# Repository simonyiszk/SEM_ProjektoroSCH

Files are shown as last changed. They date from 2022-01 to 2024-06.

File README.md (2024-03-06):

# RS232 Remote control
This project is created for wall mounted remote control of a projector's power settings and input selection.

## Protocol basics:
RS232 in a nutshell: https://docs.google.com/document/d/1p7Dz5NA0ECTMzfMRH148HRk15ERgRvAex5ETr_D8jeQ/edit?usp=sharing

## Project workflow:
- [x] Schematic design
- [ ] Firmwware developent
- [ ] Case design
- [ ] Protoype testing

## Project is made possible by Schönherz Elektronikai Műhely (SEM)

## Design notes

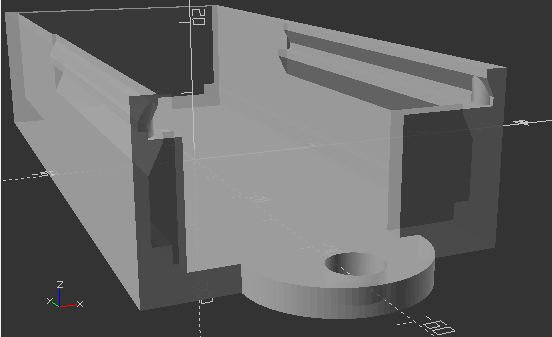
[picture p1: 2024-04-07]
Doboz/doboz_v5_becsusztatos_pattintos_3.jpg

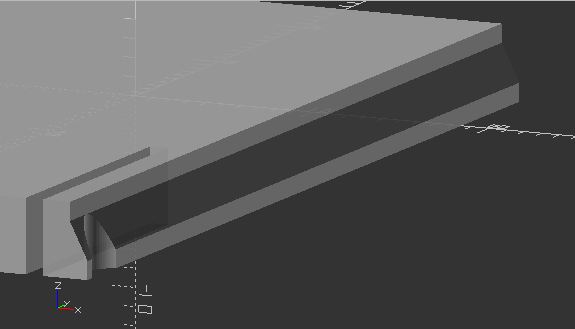
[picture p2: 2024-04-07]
Doboz/doboz_v5_becsusztatos_pattintos_2.jpg

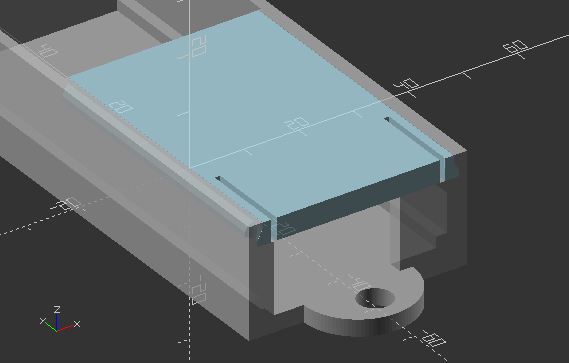
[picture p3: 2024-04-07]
Doboz/doboz_v5_becsusztatos_pattintos_4.jpg

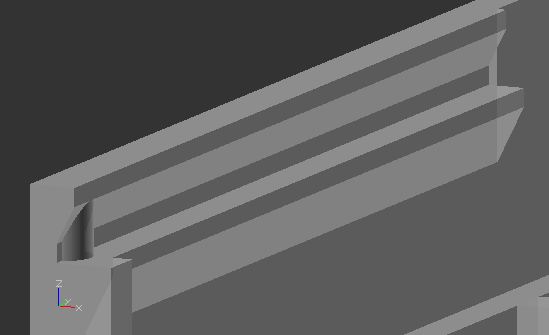
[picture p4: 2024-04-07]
Doboz/doboz_v5_becsusztatos_pattintos_1.jpg

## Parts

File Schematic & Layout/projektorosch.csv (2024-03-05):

Reference | Value | Footprint | Datasheet | Lcsc | Lscs | Qty
C1 | 0.1uF | Capacitor_SMD:C_0805_2012Metric_Pad1.18x1.45mm_HandSolder | ~ |  |  | 1
C2 | 0.1uF | Capacitor_SMD:C_0805_2012Metric_Pad1.18x1.45mm_HandSolder | ~ |  |  | 1
C3 | 0.1uF | Capacitor_SMD:C_0805_2012Metric_Pad1.18x1.45mm_HandSolder | ~ |  | C282730 | 1
C4 | 0.1uF | Capacitor_SMD:C_0805_2012Metric_Pad1.18x1.45mm_HandSolder | ~ |  |  | 1
C5 | 0.1uF | Capacitor_SMD:C_0805_2012Metric_Pad1.18x1.45mm_HandSolder | ~ |  |  | 1
C6 | 0.1uF | Capacitor_SMD:C_0805_2012Metric_Pad1.18x1.45mm_HandSolder | ~ |  |  | 1
C7 | 0.1uF | Capacitor_SMD:C_0805_2012Metric_Pad1.18x1.45mm_HandSolder | ~ |  |  | 1
C8 | 0.1uF | Capacitor_SMD:C_0805_2012Metric_Pad1.18x1.45mm_HandSolder | ~ |  | C6641151 | 1
C9 | 22pF | Capacitor_SMD:C_0805_2012Metric_Pad1.18x1.45mm_HandSolder | ~ |  | C190088 | 1
C10 | 22pF | Capacitor_SMD:C_0805_2012Metric_Pad1.18x1.45mm_HandSolder | ~ |  |  | 1
J1 | Power | Connector_Phoenix_MC:PhoenixContact_MC_1,5_2-G-3.5_1x02_P3.50mm_Horizontal | ~ |  |  | 1
J2 | RS232 | Connector_Phoenix_MC:PhoenixContact_MC_1,5_3-G-3.5_1x03_P3.50mm_Horizontal | ~ |  |  | 1
J3 | Programmer | Connector_PinHeader_2.54mm:PinHeader_1x06_P2.54mm_Vertical | ~ |  |  | 1
J4 | ISP | Connector_PinHeader_2.54mm:PinHeader_2x03_P2.54mm_Vertical | ~ |  |  | 1
R1 | 150 | Resistor_SMD:R_0805_2012Metric_Pad1.20x1.40mm_HandSolder | ~ |  |  | 1
R2 | 150 | Resistor_SMD:R_0805_2012Metric_Pad1.20x1.40mm_HandSolder | ~ |  |  | 1
R3 | 150 | Resistor_SMD:R_0805_2012Metric_Pad1.20x1.40mm_HandSolder | ~ |  |  | 1
R4 | 150 | Resistor_SMD:R_0805_2012Metric_Pad1.20x1.40mm_HandSolder | ~ |  |  | 1
R5 | 10k | Resistor_SMD:R_0805_2012Metric_Pad1.20x1.40mm_HandSolder | ~ |  |  | 1
R6 | 10k | Resistor_SMD:R_0805_2012Metric_Pad1.20x1.40mm_HandSolder | ~ |  |  | 1
R7 | 10k | Resistor_SMD:R_0805_2012Metric_Pad1.20x1.40mm_HandSolder | ~ |  |  | 1
R8 | 10k | Resistor_SMD:R_0805_2012Metric_Pad1.20x1.40mm_HandSolder | ~ |  |  | 1
R9 | 10k | Resistor_SMD:R_0805_2012Metric_Pad1.20x1.40mm_HandSolder | ~ |  |  | 1
SW1 | Input 1 | Library:Marquardt 64250101 | ~ |  |  | 1
SW2 | Input 2 | Library:Marquardt 64250101 | ~ |  |  | 1
SW3 | Power off | Library:Marquardt 64250101 | ~ |  |  | 1
SW4 | Power on | Library:Marquardt 64250101 | ~ |  |  | 1
SW5 | Reset | Button_Switch_SMD:SW_Push_1P1T_NO_6x6mm_H9.5mm | ~ |  | C255812 | 1
TP1 | 5V | TestPoint:TestPoint_Pad_D2.5mm | ~ |  |  | 1
TP2 | GND | TestPoint:TestPoint_Pad_D2.5mm | ~ |  |  | 1
TP3 | 232-RX | TestPoint:TestPoint_Pad_D2.5mm | ~ |  |  | 1
TP4 | 232-TX | TestPoint:TestPoint_Pad_D2.5mm | ~ |  |  | 1
U1 | MAX232 | Package_SO:SOP-16_3.9x9.9mm_P1.27mm | http://www.ti.com/lit/ds/symlink/max232.pdf |  | C519083 | 1
U2 | ATmega328P-A | Package_QFP:TQFP-32_7x7mm_P0.8mm | http://ww1.microchip.com/downloads/en/DeviceDoc/ATmega328_P%20AVR%20MCU%20with%20picoPower%20Technology%20Data%20Sheet%2040001984A.pdf |  | C132230 | 1
Y1 | 16MHz | Crystal:Crystal_SMD_HC49-SD_HandSoldering | ~ | C2975360 |  | 1

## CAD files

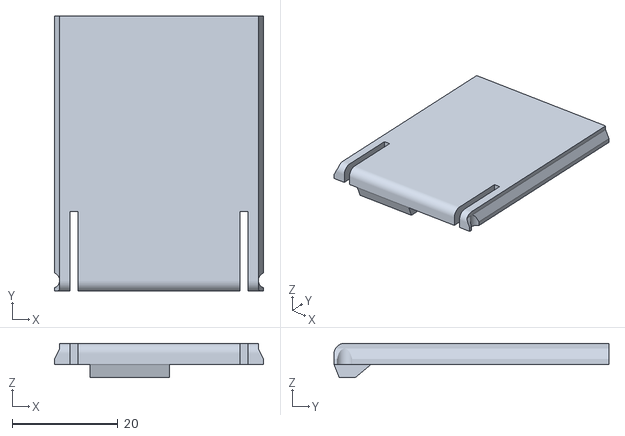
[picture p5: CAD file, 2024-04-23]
Doboz/doboz_v6_felso.stl
39.6 x 52.0 x 6.50

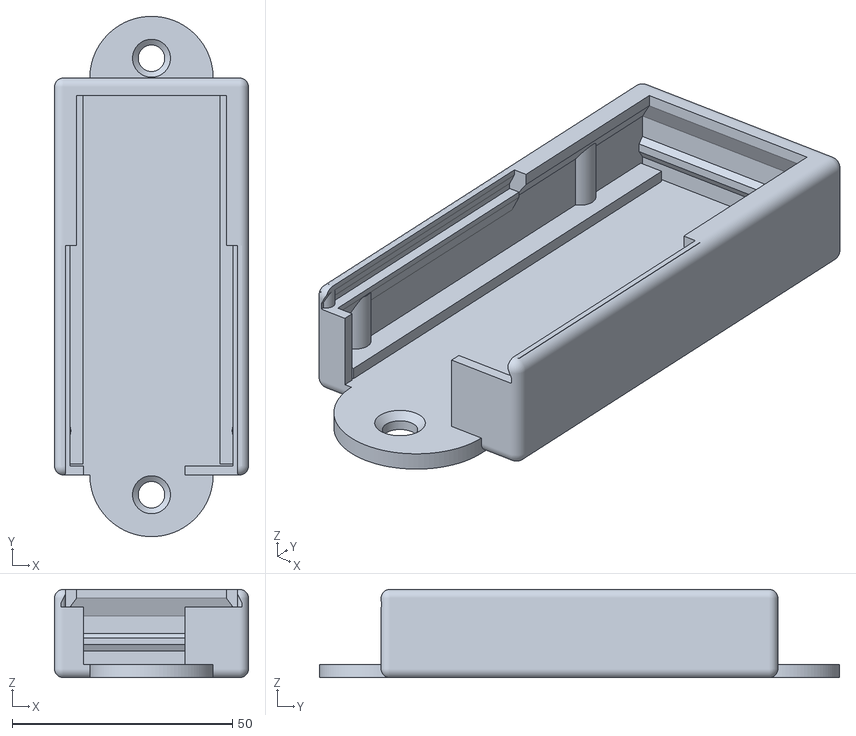
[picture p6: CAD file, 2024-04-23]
Doboz/doboz_v6_also.stl
44.0 x 118.0 x 20.0

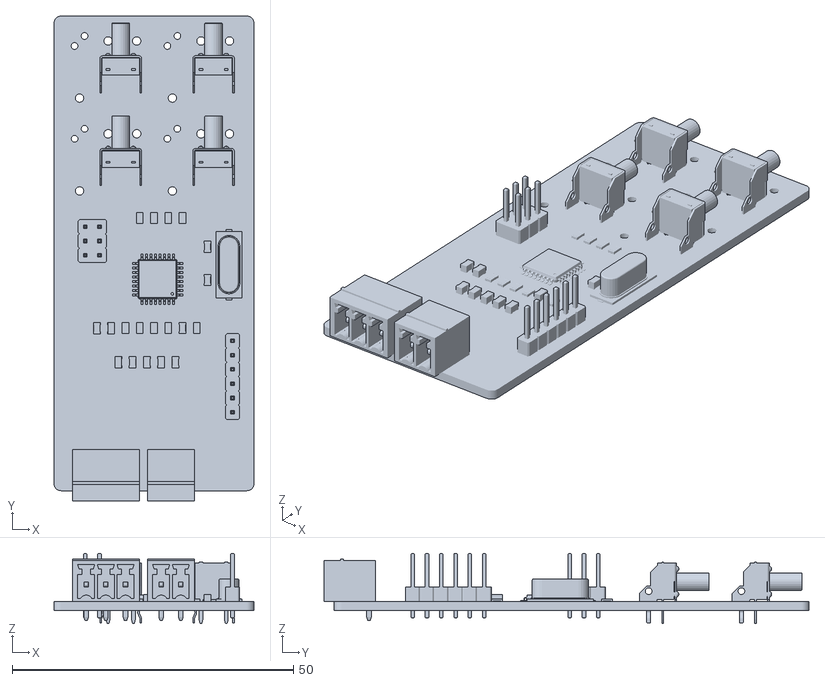
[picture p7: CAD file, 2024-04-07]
Doboz/doboz_v4-elektronika_3d.stl
35.6 x 86.3 x 12.5

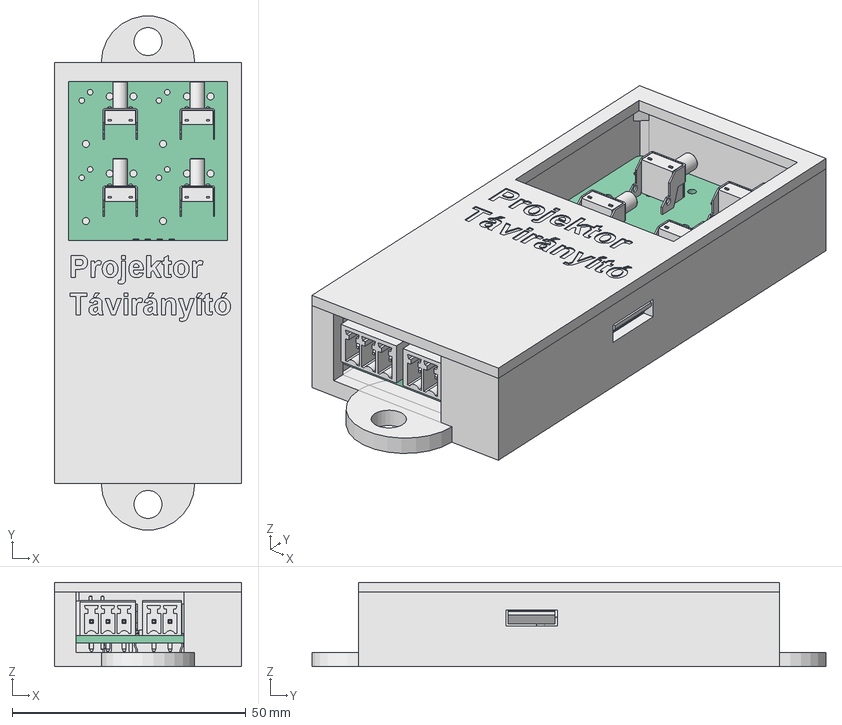
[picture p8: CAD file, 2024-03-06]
Doboz/doboz_v4.FCStd
40.0 x 109.9 x 18.0 mm
Pcb_c95c
J2_MC_01x03_G_3_5mm_12e7bac8dbaf
R8_R_0805_2012Metric_695cc4dfc1c9 x 9
Y1_Crystal_SMD_HC49-SD_3ddabce48a06
C1_C_0805_2012Metric_832210f2bbc2 x 10
U2_TQFP_32_7x7mm_P08mm_a250dbf983b6
J1_MC_01x02_G_3_5mm_f8f39d346681
SW4_SW_Tactile_SPST_Angled_PTS645Vx83-2LFS_4b6979eed0d8 x 4
J3_PinHeader_1x06_P254mm_Vertical_726634c3bc6e
J4_PinHeader_2x03_P254mm_Vertical_2c30eb3d481b
Also
Felso2

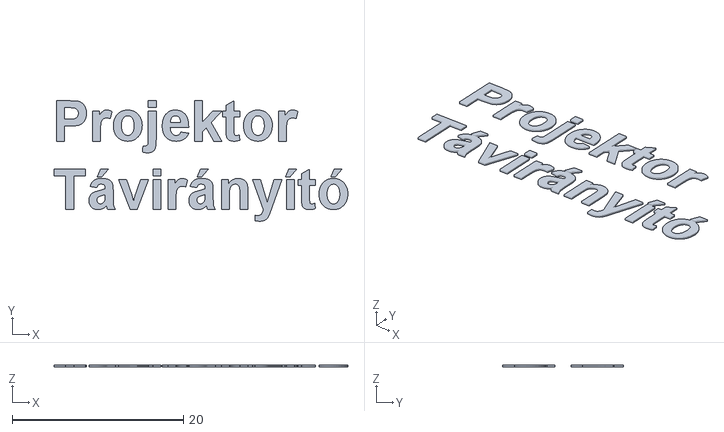
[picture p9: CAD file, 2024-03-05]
Doboz/doboz_v4-Felirat001.stl
34.4 x 14.1 x 0.2

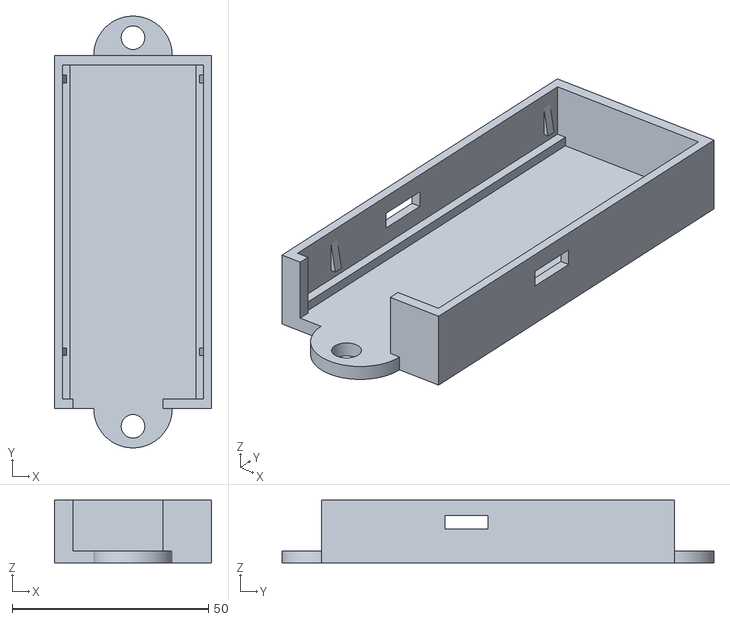
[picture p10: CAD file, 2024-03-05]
Doboz/doboz_v4-Also2.stl
40.0 x 110.0 x 16.0

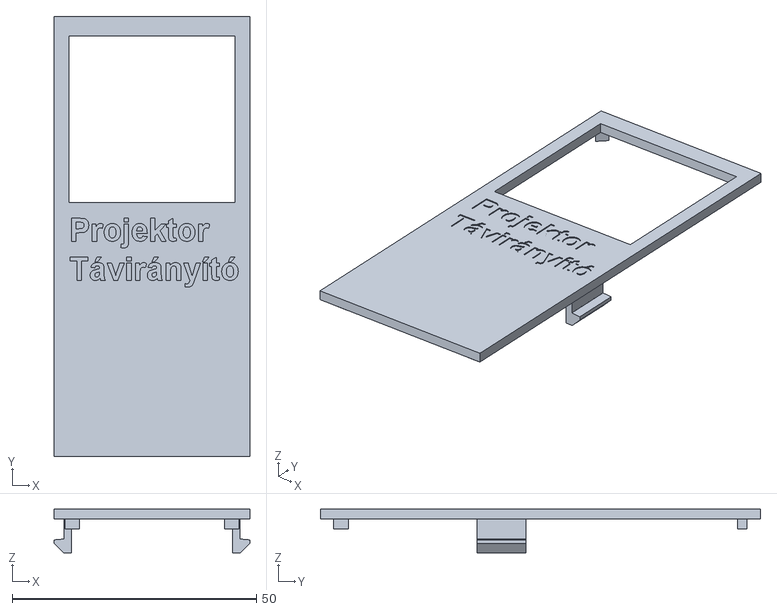
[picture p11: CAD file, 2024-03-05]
Doboz/doboz_v4-Felso2.stl
40.0 x 90.0 x 8.90

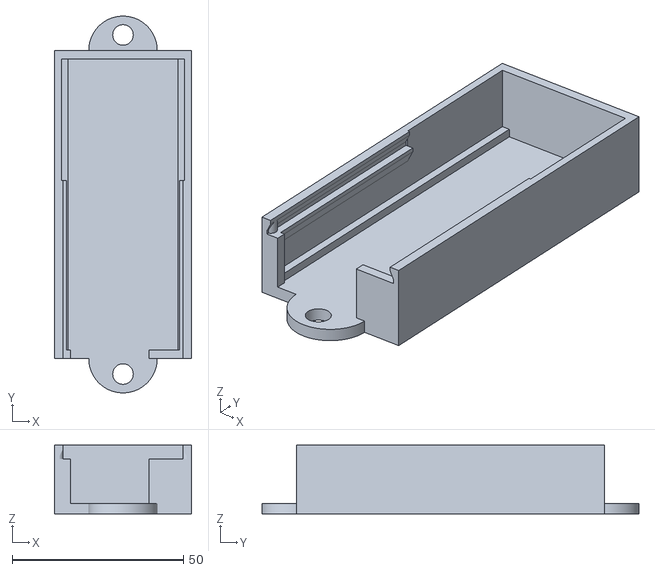
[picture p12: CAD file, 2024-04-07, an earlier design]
Doboz/doboz_v5_also.stl
40.0 x 110.0 x 20.0

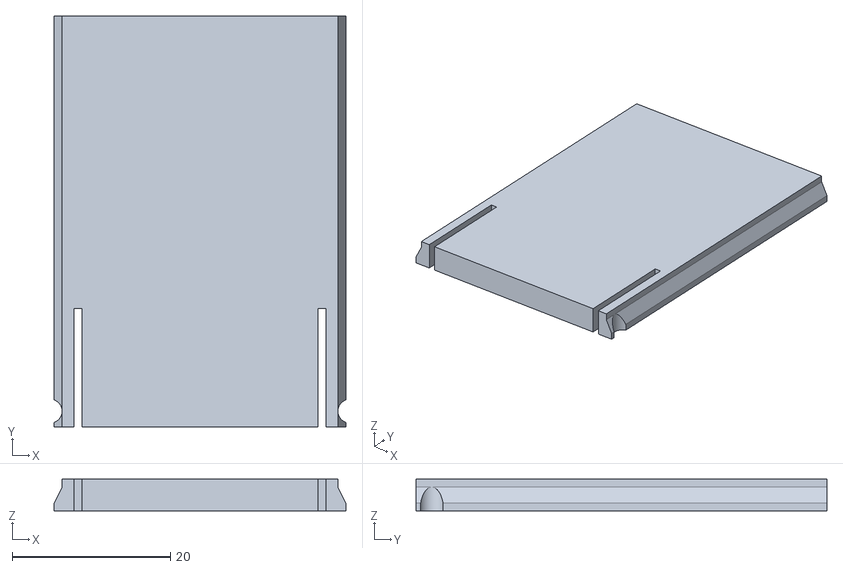
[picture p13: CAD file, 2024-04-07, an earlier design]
Doboz/doboz_v5_felso.stl
36.9 x 52.0 x 4.00

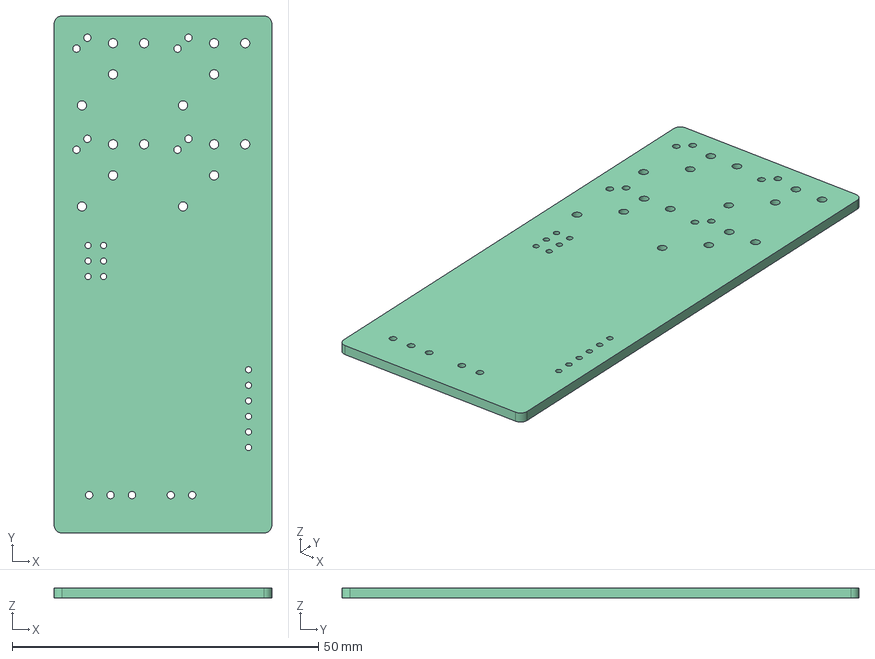
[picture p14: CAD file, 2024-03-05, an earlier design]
Doboz/doboz_v1.FCStd
35.6 x 84.5 x 1.60 mm

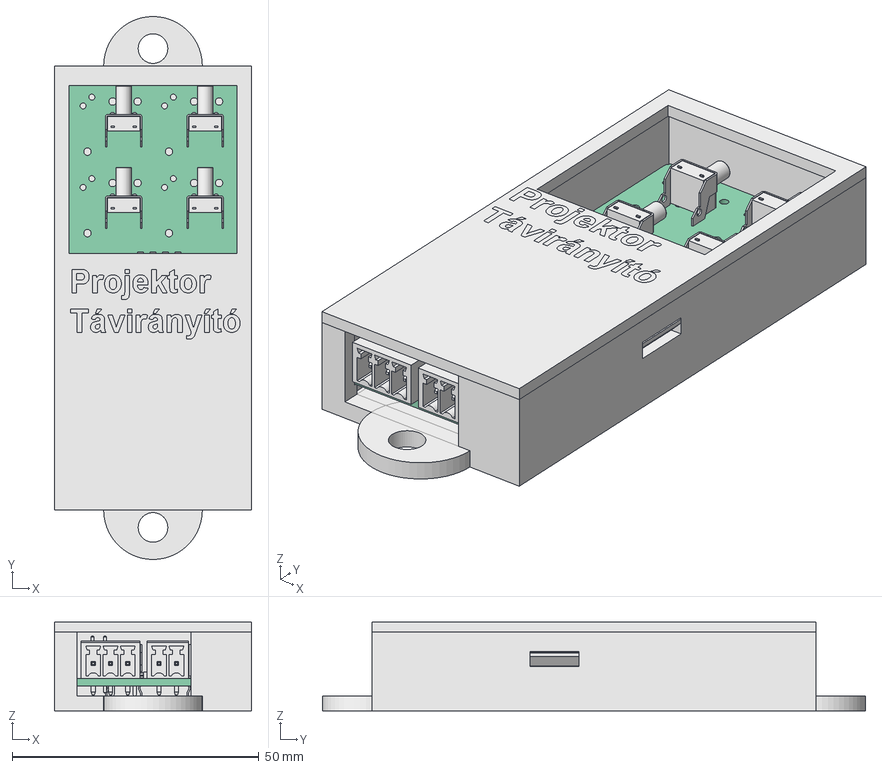
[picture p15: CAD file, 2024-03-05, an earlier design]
Doboz/doboz_v3.FCStd
40.0 x 110.0 x 20.0 mm
Pcb_c95c
J2_MC_01x03_G_3_5mm_12e7bac8dbaf
R8_R_0805_2012Metric_695cc4dfc1c9 x 9
Y1_Crystal_SMD_HC49-SD_3ddabce48a06
C1_C_0805_2012Metric_832210f2bbc2 x 10
U2_TQFP_32_7x7mm_P08mm_a250dbf983b6
J1_MC_01x02_G_3_5mm_f8f39d346681
SW4_SW_Tactile_SPST_Angled_PTS645Vx83-2LFS_4b6979eed0d8 x 4
J3_PinHeader_1x06_P254mm_Vertical_726634c3bc6e
J4_PinHeader_2x03_P254mm_Vertical_2c30eb3d481b
Also
Felso
ShapeString
ShapeString001

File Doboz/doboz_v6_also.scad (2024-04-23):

//OpenSCAD source code
//https://openscad.org

//color("red",0.8) translate([0,0,0]) import("doboz_v4-Also2.stl");
//color("pink",0.8)translate([0,0,0]) import("doboz_v4-Felso2.stl");
color("lightgreen",0.8) translate([0,0,0]) import("doboz_v4-elektronika_3d.stl");
color("lightblue",0.8) translate([0,0,0]) import("doboz_v6_felso.stl");

//HA JOBBAN ÁT SZERETNÉD LÁTNI MI HOGY VAN, KAPCSOLD BE EZEKET:
$ATTEKINTO_NEZET=false;
$FELBEVAGOTT_NEZET=false;

$fn=15; //ÍV FELBONTÁS - STL-BE EXPORTÁLÁS ELŐTT VEDD FEL PL. 100-ra!
//(jelentősen több ideig fog generálni, úgyhogy az EXPORTÁLÁS LÉPÉSEI:
//kikommenteled az importokat; átírod $fn=100-ra; rányomsz a "render" gombra (vagy F6); megvárod míg legenerálja; File->Export; aztán Ctrl+Z amennyiszer kell)

//Szélesség állításnál az alsó nyáktartó peremeket kézzel kell igazítani
//
//Hosszúság állításánál  fenti részt tartó vezetősíneket és a gomb mlletti takrókt kézzel kell átméretezni
//
//A felső rész módosításakor ne felejtsd el átmásolni innen a konstansokat!
//

$lekerekites=2;
$belso_hossz=86;
$belso_szel=40;
$kulso_mag=20;
$anyagvastagsag_oldalfal=2;
$anyagvastagsag_alja=3;
$henger_sugar=14;
$henger_luk=3;
$felso_resz_hossz=50; //+anyagvastagsag_oldalfal

color("#b0b0b0",0.8)
render(){


difference(){//alsó rész mínusz felső rész
	//alsó rész:
	union(){
		
		
		difference(){
			union(){
				//alap téglatest, amiből ki lesz vonva a belső rész:
				translate([0,0,10])
				if($ATTEKINTO_NEZET==false)
					cube([$belso_szel+2*$anyagvastagsag_oldalfal,$belso_hossz+2*$anyagvastagsag_oldalfal,$kulso_mag], center=true);

				//fél hengerek a talpon a rögzítéshez:
				translate([0,$belso_hossz/2+$anyagvastagsag_oldalfal,$anyagvastagsag_alja/2])
					difference(){
						cylinder(r=$henger_sugar,h=$anyagvastagsag_alja,center=true);
						translate([0,4.5,0])
							cylinder(r=$henger_luk,h=$anyagvastagsag_alja,center=true);
						//felfogató csavar süllyesztés (45 fokos kúp):
						translate([0,4.5,+2.2])
							cylinder(r1=0,r2=10,h=10,center=true);
					}
				translate([0,-$belso_hossz/2-$anyagvastagsag_oldalfal,$anyagvastagsag_alja/2])
					difference(){
						cylinder(r=$henger_sugar,h=$anyagvastagsag_alja,center=true);
						translate([0,-4.5,0])
							cylinder(r=$henger_luk,h=$anyagvastagsag_alja,center=true);
						translate([0,-4.5,+2.2])
							cylinder(r1=0,r2=10,h=10,center=true);
					}
			}
			
			//oldalfalból kivágott hely csatlakozóknak:
			translate([-15.4,-45.001,$anyagvastagsag_alja])
				cube([23,2.502,30],center=false);
			
			//középső üreg:
			translate([0,0,$anyagvastagsag_alja+1000/2])
				cube([$belso_szel,$belso_hossz,1000], center=true);
			//lekerekítések:
			{
			//bal oldal:
			
			//alsó lekerekítések:
			translate([(-$belso_szel/2)-$anyagvastagsag_oldalfal+$lekerekites/2,0,$lekerekites/2])
				el_lekerekites_negativ($lekerekites,$belso_hossz+2*$anyagvastagsag_oldalfal);
			translate([-$belso_szel/2,-$belso_hossz/2-$anyagvastagsag_oldalfal+$lekerekites/2,$lekerekites/2])
				rotate([0,0,90])
					el_lekerekites_negativ($lekerekites,2*($belso_szel/2-$henger_sugar));
			translate([-$belso_szel/2,+$belso_hossz/2+$anyagvastagsag_oldalfal-$lekerekites/2,$lekerekites/2])
				rotate([0,0,-90])
					el_lekerekites_negativ($lekerekites,2*($belso_szel/2-$henger_sugar));
			translate([-$belso_szel/2-$anyagvastagsag_oldalfal+$lekerekites/2,-$belso_hossz/2-$anyagvastagsag_oldalfal+$lekerekites/2,$lekerekites/2])
				rotate([0,0,0])
					sarok_legombolyites_negativ($lekerekites);
			translate([-$belso_szel/2-$anyagvastagsag_oldalfal+$lekerekites/2,+$belso_hossz/2+$anyagvastagsag_oldalfal-$lekerekites/2,$lekerekites/2])
				rotate([0,0,-90])
					sarok_legombolyites_negativ($lekerekites);
			//oldalsó lekerekítések:
			translate([-$belso_szel/2-$anyagvastagsag_oldalfal+$lekerekites/2,-$belso_hossz/2-$anyagvastagsag_oldalfal+$lekerekites/2,$kulso_mag/2])
				rotate([90,0,90])
					el_lekerekites_negativ($lekerekites,$kulso_mag);
			translate([-$belso_szel/2-$anyagvastagsag_oldalfal+$lekerekites/2,+$belso_hossz/2+$anyagvastagsag_oldalfal-$lekerekites/2,$kulso_mag/2])
				rotate([90,0,0])
					el_lekerekites_negativ($lekerekites,$kulso_mag);
			//felső lekerekítések:
			translate([(-$belso_szel/2)-$anyagvastagsag_oldalfal+$lekerekites/2,0,$kulso_mag-$lekerekites/2])
				rotate([0,90,0])
					el_lekerekites_negativ($lekerekites,$belso_hossz+2*$anyagvastagsag_oldalfal);
			translate([-$belso_szel/2-$anyagvastagsag_oldalfal,-$belso_hossz/2-$anyagvastagsag_oldalfal+$lekerekites/2,$kulso_mag-$lekerekites/2])
				rotate([0,90,90])
					el_lekerekites_negativ($lekerekites,$belso_szel/2+$anyagvastagsag_oldalfal);
			translate([0,+$belso_hossz/2+$anyagvastagsag_oldalfal-$lekerekites/2,$kulso_mag-$lekerekites/2])
				rotate([0,90,-90])
					el_lekerekites_negativ($lekerekites,$belso_szel+2*$anyagvastagsag_oldalfal);
			translate([-$belso_szel/2-$anyagvastagsag_oldalfal+$lekerekites/2,-$belso_hossz/2-$anyagvastagsag_oldalfal+$lekerekites/2,$kulso_mag-$lekerekites/2])
				rotate([0,90,0])
					sarok_legombolyites_negativ($lekerekites);
			translate([-$belso_szel/2-$anyagvastagsag_oldalfal+$lekerekites/2,+$belso_hossz/2+$anyagvastagsag_oldalfal-$lekerekites/2,$kulso_mag-$lekerekites/2])
				rotate([0,90,-90])
					sarok_legombolyites_negativ($lekerekites);
			
			
			//jobb oldal:
			mirror([1,0,0]){
			
			
			//alsó lekerekítések:
			translate([(-$belso_szel/2)-$anyagvastagsag_oldalfal+$lekerekites/2,0,$lekerekites/2])
				el_lekerekites_negativ($lekerekites,$belso_hossz+2*$anyagvastagsag_oldalfal);
			translate([-$belso_szel/2,-$belso_hossz/2-$anyagvastagsag_oldalfal+$lekerekites/2,$lekerekites/2])
				rotate([0,0,90])
					el_lekerekites_negativ($lekerekites,2*($belso_szel/2-$henger_sugar));
			translate([-$belso_szel/2,+$belso_hossz/2+$anyagvastagsag_oldalfal-$lekerekites/2,$lekerekites/2])
				rotate([0,0,-90])
					el_lekerekites_negativ($lekerekites,2*($belso_szel/2-$henger_sugar));
			translate([-$belso_szel/2-$anyagvastagsag_oldalfal+$lekerekites/2,-$belso_hossz/2-$anyagvastagsag_oldalfal+$lekerekites/2,$lekerekites/2])
				rotate([0,0,0])
					sarok_legombolyites_negativ($lekerekites);
			translate([-$belso_szel/2-$anyagvastagsag_oldalfal+$lekerekites/2,+$belso_hossz/2+$anyagvastagsag_oldalfal-$lekerekites/2,$lekerekites/2])
				rotate([0,0,-90])
					sarok_legombolyites_negativ($lekerekites);
			//oldalsó lekerekítések:
			translate([-$belso_szel/2-$anyagvastagsag_oldalfal+$lekerekites/2,-$belso_hossz/2-$anyagvastagsag_oldalfal+$lekerekites/2,$kulso_mag/2])
				rotate([90,0,90])
					el_lekerekites_negativ($lekerekites,$kulso_mag);
			translate([-$belso_szel/2-$anyagvastagsag_oldalfal+$lekerekites/2,+$belso_hossz/2+$anyagvastagsag_oldalfal-$lekerekites/2,$kulso_mag/2])
				rotate([90,0,0])
					el_lekerekites_negativ($lekerekites,$kulso_mag);
			//felső lekerekítések:
			translate([(-$belso_szel/2)-$anyagvastagsag_oldalfal+$lekerekites/2,0,$kulso_mag-$lekerekites/2])
				rotate([0,90,0])
					el_lekerekites_negativ($lekerekites,$belso_hossz+2*$anyagvastagsag_oldalfal);
			translate([-$belso_szel/2-$anyagvastagsag_oldalfal,-$belso_hossz/2-$anyagvastagsag_oldalfal+$lekerekites/2,$kulso_mag-$lekerekites/2])
				rotate([0,90,90])
					el_lekerekites_negativ($lekerekites,$belso_szel/2+$anyagvastagsag_oldalfal);
			translate([0,+$belso_hossz/2+$anyagvastagsag_oldalfal-$lekerekites/2,$kulso_mag-$lekerekites/2])
				rotate([0,90,-90])
					el_lekerekites_negativ($lekerekites,$belso_szel+2*$anyagvastagsag_oldalfal);
			translate([-$belso_szel/2-$anyagvastagsag_oldalfal+$lekerekites/2,-$belso_hossz/2-$anyagvastagsag_oldalfal+$lekerekites/2,$kulso_mag-$lekerekites/2])
				rotate([0,90,0])
					sarok_legombolyites_negativ($lekerekites);
			translate([-$belso_szel/2-$anyagvastagsag_oldalfal+$lekerekites/2,+$belso_hossz/2+$anyagvastagsag_oldalfal-$lekerekites/2,$kulso_mag-$lekerekites/2])
				rotate([0,90,-90])
					sarok_legombolyites_negativ($lekerekites);
			}//mirror (lekerekítések)
			}//lekerekítések
		}//difference
		//felső részt alulról tartó háromszög sávok:
		translate([-$belso_szel/2-0,7,12])
			rotate([90,0,0])
				linear_extrude(50)
				polygon([ [0,0], [1.5,3], [1.5,4], [0,4] ]);
		mirror([1,0,0])
		translate([-$belso_szel/2-0,7,12])
			rotate([90,0,0])
				linear_extrude(50)
				polygon([ [0,0], [1.5,3], [1.5,4], [0,4] ]);
		//felső részt felülrőlról tartó háromszög sávok:
		translate([-$belso_szel/2-0.5,7,17])
			rotate([90,0,0])
				linear_extrude(50)
				polygon([ [0,0], [1,2], [1,3], [0,3] ]);
		mirror([1,0,0])
		translate([-$belso_szel/2-0.5,7,17])
			rotate([90,0,0])
				linear_extrude(50)
				polygon([ [0,0], [1,2], [1,3], [0,3] ]);
		//belső perem lent két oldalt:
		$perem_szel=4.5;
		$perem_mag=2;
		translate([-$belso_szel/2+$perem_szel/2,0,+$anyagvastagsag_alja+$perem_mag/2])
			cube([$perem_szel,85,2], center=true);
		translate([+$belso_szel/2-$perem_szel/2,0,+$anyagvastagsag_alja+$perem_mag/2])
			cube([$perem_szel,85,2], center=true);
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

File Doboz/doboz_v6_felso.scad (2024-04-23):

//OpenSCAD source code
//https://openscad.org

//import("C:/SEM_Simonyi/SEM_ProjektoroSCH-main/Doboz/doboz_v5_also.scad");

$fn=100;

//Mennyivel legyen keskenyebb a nyomtatott felső darab az alsóban neki kialakított helynél (x2, azaz mindkét oldalból levon ennyit)? Ha nem fér be, feszül, akkor növeld az értéket.
$oldalso_kisebbites=0.7;

$lekerekites=2;
$belso_hossz=86;
$belso_szel=40;
$kulso_mag=20;
$anyagvastagsag_oldalfal=2;
$anyagvastagsag_alja=3;
$henger_sugar=14;
$henger_luk=3;
$felso_resz_hossz=50; //+anyagvastagsag_oldalfal

translate([0,-$belso_hossz/2-$anyagvastagsag_oldalfal,16])
color("#b0b0b0",0.8)
render(){
//TODO: hosszúság rövidebbre vétele, hogy biztosan bepattanjon

difference(){
	//trapéz-szerű alap:
	union(){
		translate([0,$felso_resz_hossz+$anyagvastagsag_oldalfal,0])
			rotate([90,0,0])
				linear_extrude($felso_resz_hossz+$anyagvastagsag_oldalfal)
				polygon([ 
					[-$belso_szel/2-0.5+$oldalso_kisebbites,0],
					[+$belso_szel/2+0.5-$oldalso_kisebbites,0],
					[+$belso_szel/2+0.5-$oldalso_kisebbites,1],
					[+$belso_szel/2-0.5-$oldalso_kisebbites,3],
					[+$belso_szel/2-0.5-$oldalso_kisebbites,4],
					[-$belso_szel/2+0.5+$oldalso_kisebbites,4],
					[-$belso_szel/2+0.5+$oldalso_kisebbites,3],
					[-$belso_szel/2-0.5+$oldalso_kisebbites,1] ]);
		//csatlakozókat leszorító kiálló rész az alján
		translate([-13,0,0])
			rotate([90,0,0])
			rotate([0,90,0])
				linear_extrude(15)
				polygon([ 
					[0,0],
					[1,-2.5],
					[4,-2.5],
					[7,0] ]);
	}

	//fél henger pöckök a rögzítéshez:
	translate([$belso_szel/2+$anyagvastagsag_oldalfal/2-$oldalso_kisebbites,2,1.5])
		difference(){
			cylinder(r=1.5, h=4, center=true);
			translate([0,-5,-5])cube([10,10,10]);
		}
	mirror([1,0,0])
	translate([$belso_szel/2+$anyagvastagsag_oldalfal/2-$oldalso_kisebbites,2,1.5])
		difference(){
			cylinder(r=1.5, h=4, center=true);
			translate([0,-5,-5])cube([10,10,10]);
		}
	//bevágások a hajlékonysághoz a rögzítésnél
	translate([0.40*$belso_szel-$oldalso_kisebbites,0,0])
		cube([1.5,15,4]);
	mirror([1,0,0])
	translate([0.40*$belso_szel-$oldalso_kisebbites,0,0])
		cube([1.5,15,4]);
	//felső lekerekítés a elejénél:
	translate([0,$lekerekites/2,4-$lekerekites/2])
		rotate([0,180,-90])
			el_lekerekites_negativ($lekerekites,$belso_szel+2*$anyagvastagsag_oldalfal);
}


}//render

module sarok_legombolyites_negativ(r,center=true){
	if(center==true){
		translate([r/2,r/2,r/2])
		rotate([0,90,180])
			difference(){
				cube(r);
				sphere(r);
			}
	}else if(center==false){
		rotate([0,90,180])
			difference(){
				cube(r);
				sphere(r);
			}
	}
}
module el_lekerekites_negativ(r,hossz,center=true){
	if(center==true){
	translate([r/2,-hossz/2,r/2])
		rotate([0,180,0])
			difference(){
			cube([r,hossz,r]);
			translate([0,-0.5,0])
				rotate([-90,0,0])
					cylinder(hossz+1, r, r);
			}
	}else if(center==false){
	translate([0,0,0])
		rotate([0,180,0])
			difference(){
			cube([r,hossz,r]);
			translate([0,-0.5,0])
				rotate([-90,0,0])
					cylinder(hossz+1, r, r);
			}
	}
}

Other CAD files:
Doboz/doboz_v2.FCStd
Doboz/doboz_v5_also.scad
Doboz/doboz_v5_felso.scad

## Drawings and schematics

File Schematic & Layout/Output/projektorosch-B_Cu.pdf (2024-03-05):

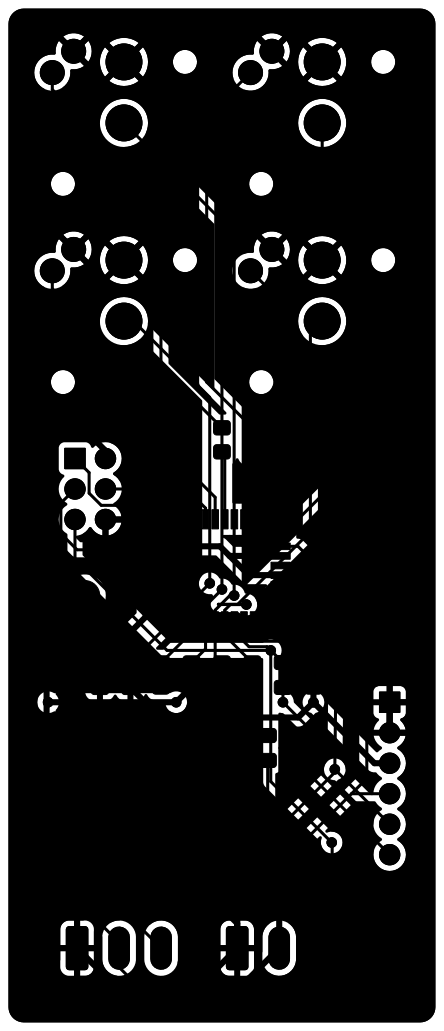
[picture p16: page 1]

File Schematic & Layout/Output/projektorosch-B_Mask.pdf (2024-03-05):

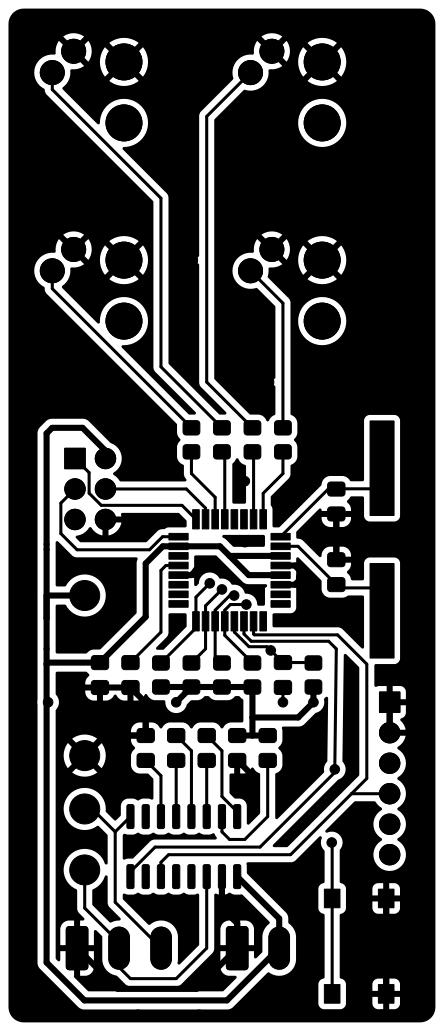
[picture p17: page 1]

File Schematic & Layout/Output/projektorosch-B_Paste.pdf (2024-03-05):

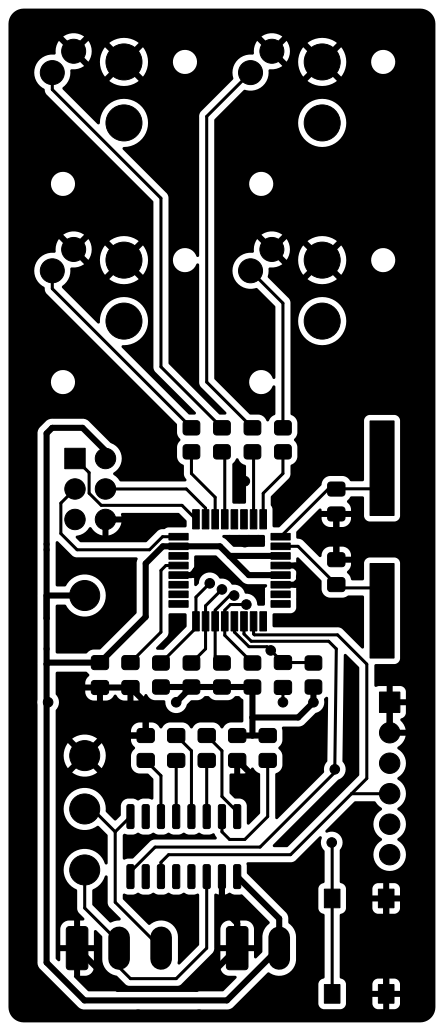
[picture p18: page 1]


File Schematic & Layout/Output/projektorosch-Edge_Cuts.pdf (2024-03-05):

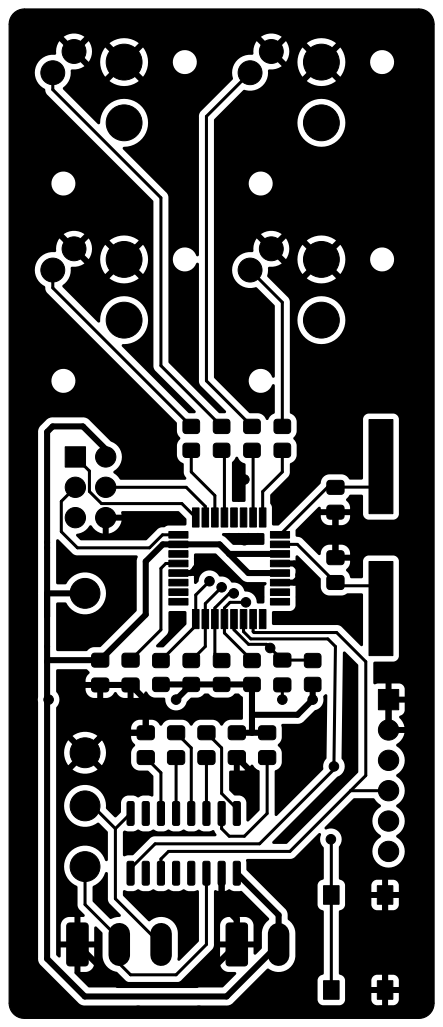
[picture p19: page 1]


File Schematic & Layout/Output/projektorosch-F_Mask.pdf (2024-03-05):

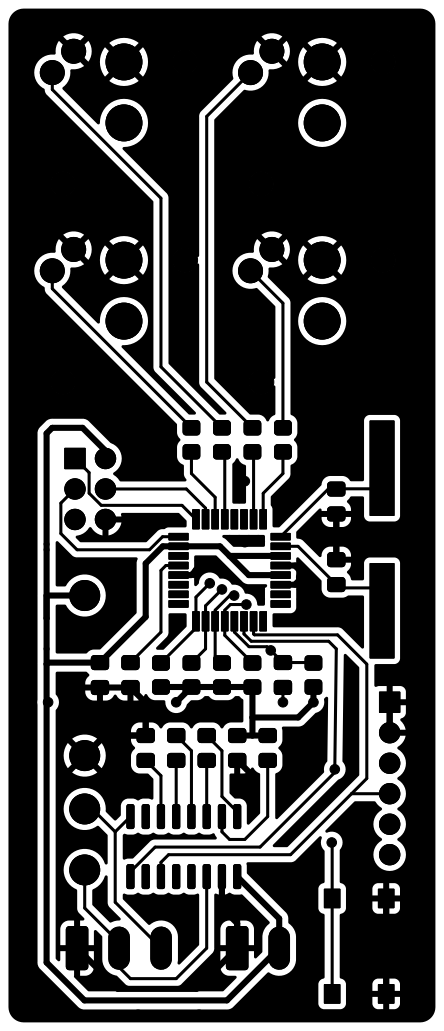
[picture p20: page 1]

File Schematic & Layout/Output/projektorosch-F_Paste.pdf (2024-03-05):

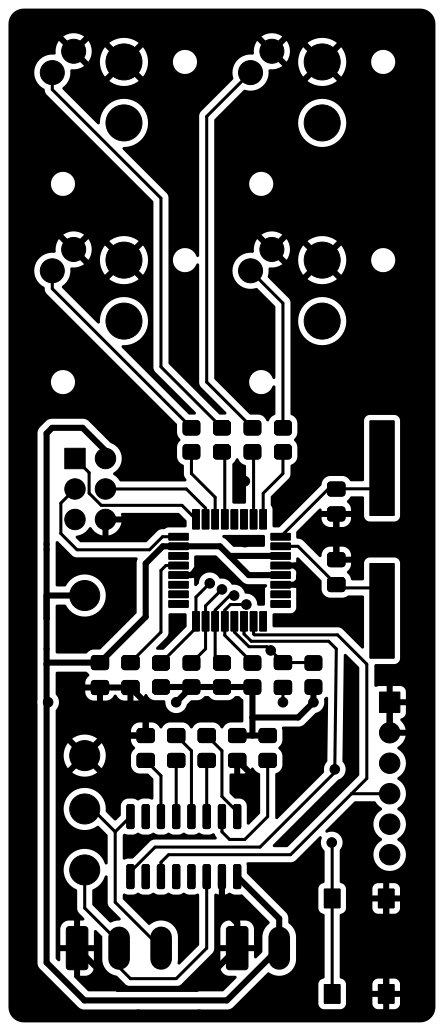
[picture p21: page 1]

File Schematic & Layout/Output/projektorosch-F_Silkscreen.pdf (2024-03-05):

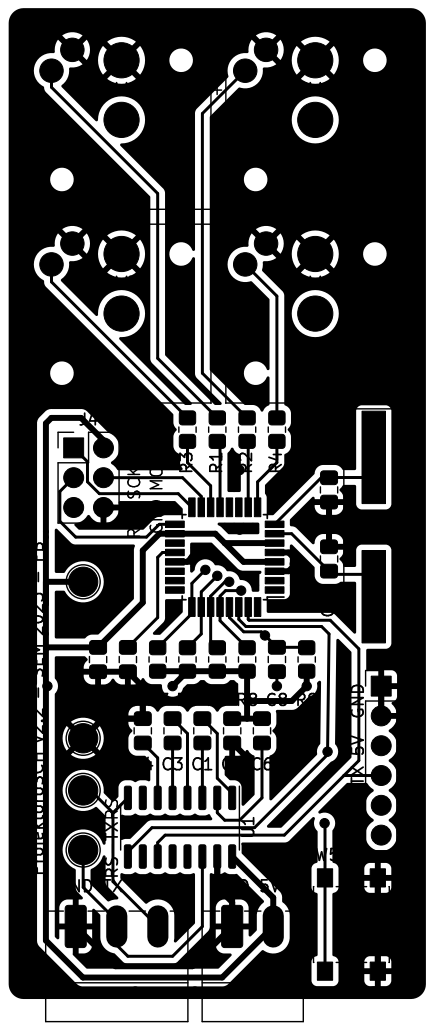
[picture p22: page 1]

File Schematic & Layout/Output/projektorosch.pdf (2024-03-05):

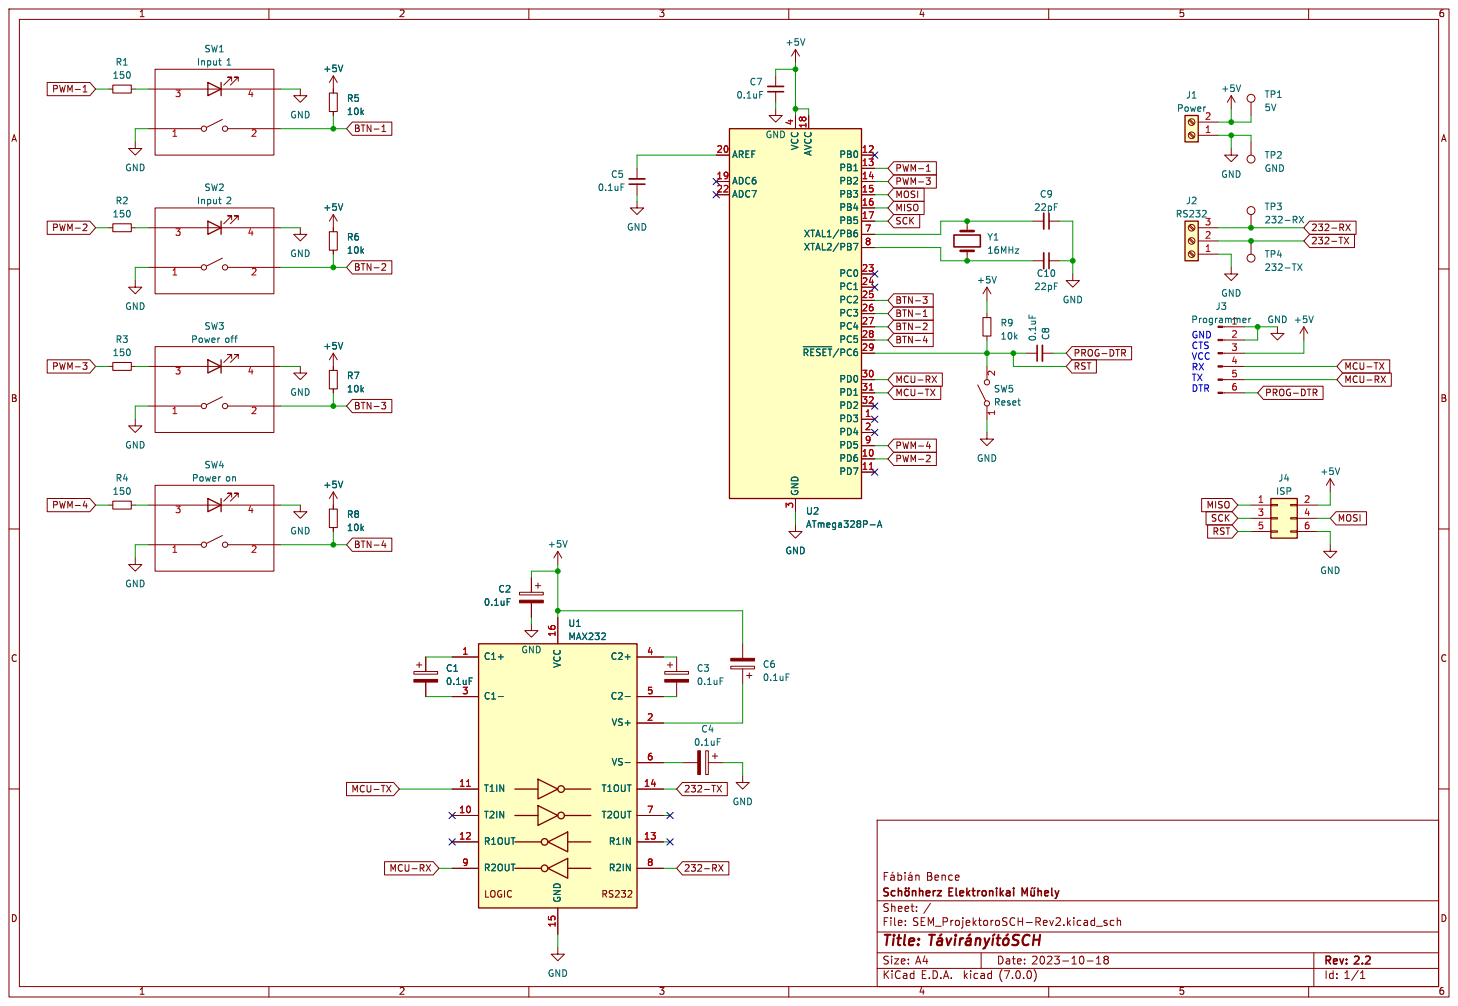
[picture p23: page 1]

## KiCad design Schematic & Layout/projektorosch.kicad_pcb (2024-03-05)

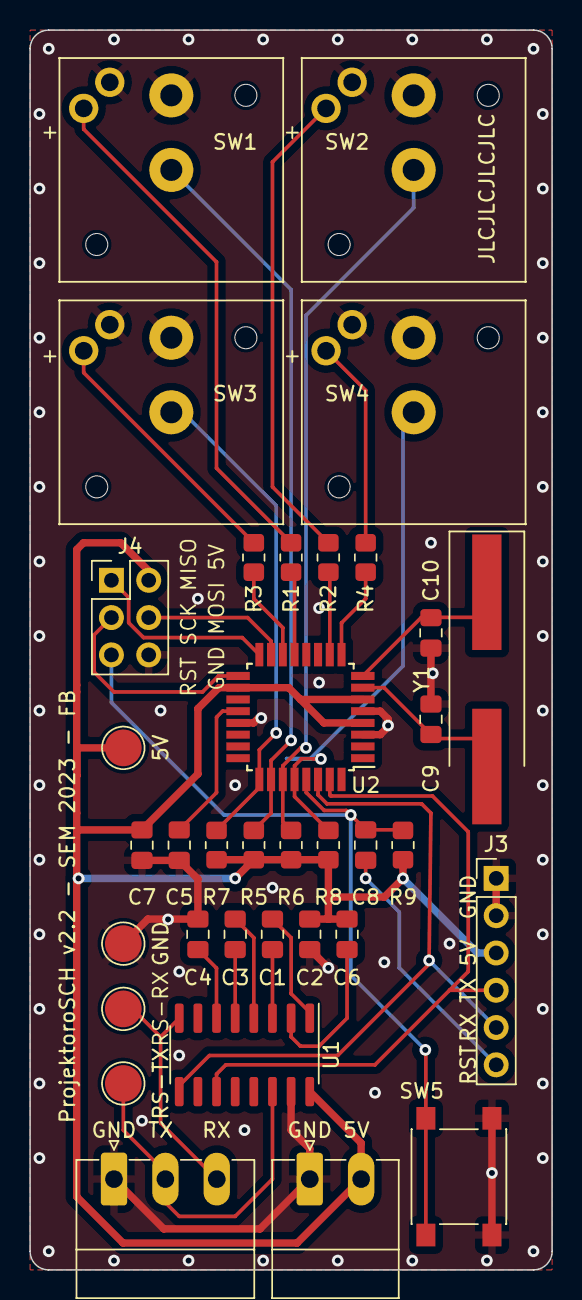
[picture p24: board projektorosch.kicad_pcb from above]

Board: 2 copper layers, 35.6 x 84.5 mm, 35 parts (0 on the bottom side), 32 nets.

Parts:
5V: 5V; TestPoint_Pad_D2.5mm
C1, C2, C3, C4, C5, C6, C7, C8: 0.1uF; C_0805_2012Metric_Pad1.18x1.45mm_HandSolder
C9, C10: 22pF; C_0805_2012Metric_Pad1.18x1.45mm_HandSolder
GND: GND; TestPoint_Pad_D2.5mm
J1: Power; PhoenixContact_MC_1,5_2-G-3.5_1x02_P3.50mm_Horizontal
J2: RS232; PhoenixContact_MC_1,5_3-G-3.5_1x03_P3.50mm_Horizontal
J3: Programmer; PinHeader_1x06_P2.54mm_Vertical
J4: ISP; PinHeader_2x03_P2.54mm_Vertical
R1, R2, R3, R4: 150; R_0805_2012Metric_Pad1.20x1.40mm_HandSolder
R5, R6, R7, R8, R9: 10k; R_0805_2012Metric_Pad1.20x1.40mm_HandSolder
RS-RX: 232-RX; TestPoint_Pad_D2.5mm
RS-TX: 232-TX; TestPoint_Pad_D2.5mm
SW1, SW2, SW3, SW4: SW_SPST; Marquardt 64250101
SW5: Reset; SW_Push_1P1T_NO_6x6mm_H9.5mm
U1: MAX232; SOP-16_3.9x9.9mm_P1.27mm
U2: ATmega328P-A; TQFP-32_7x7mm_P0.8mm
Y1: 16MHz; Crystal_SMD_HC49-SD_HandSoldering

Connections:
232-RX: J2.3, RS-RX.1, U1.8 (R2IN)
232-TX: J2.2, RS-TX.1, U1.14 (T1OUT)
+5V: 5V.1, C2.1, C6.2, C7.2, J1.2, J3.3, J4.2, R5.2, R6.2, R7.2, R8.2, R9.2, U1.16 (VCC), U2.4 (VCC), U2.6 (VCC), U2.18 (AVCC)
BTN-1: R5.1, SW1.2 (B), U2.26 (PC3)
BTN-2: R6.1, SW2.2 (B), U2.27 (PC4)
BTN-3: R7.1, SW3.2 (B), U2.25 (PC2)
BTN-4: R8.1, SW4.2 (B), U2.28 (PC5)
GND: C2.2, C4.1, C5.1, C7.1, C9.1, C10.1, GND.1, J1.1, J2.1, J3.1, J3.2, J4.6, SW1.1 (A), SW1.4 (K), SW2.1 (A), SW2.4 (K), SW3.1 (A), SW3.4 (K), SW4.1 (A), SW4.4 (K), SW5.1 (A), U1.15 (GND), U2.3 (GND), U2.5 (GND), U2.21 (GND)
MCU-RX: J3.5, U1.9 (R2OUT), U2.30 (PD0)
MCU-TX: J3.4, U1.11 (T1IN), U2.31 (PD1)
MISO: J4.1, U2.16 (PB4)
MOSI: J4.4, U2.15 (PB3)
unnamed: R1.1, SW1.3 (A)
unnamed: R2.1, SW2.3 (A)
unnamed: R3.1, SW3.3 (A)
unnamed: R4.1, SW4.3 (A)
unnamed: C1.1, U1.1 (C1+)
unnamed: C1.2, U1.3 (C1-)
unnamed: C3.1, U1.4 (C2+)
unnamed: C3.2, U1.5 (C2-)
unnamed: C6.1, U1.2 (VS+)
unnamed: C4.2, U1.6 (VS-)
unnamed: C5.2, U2.20 (AREF)
unnamed: C9.2, U2.7 (XTAL1/PB6), Y1.2
unnamed: C10.2, U2.8 (XTAL2/PB7), Y1.1
PROG-DTR: C8.2, J3.6
PWM-1: R1.2, U2.13 (PB1)
PWM-2: R2.2, U2.10 (PD6)
PWM-3: R3.2, U2.14 (PB2)
PWM-4: R4.2, U2.9 (PD5)
RST: C8.1, J4.5, R9.1, SW5.2 (B), U2.29 (~RESET/PC6)
SCK: J4.3, U2.17 (PB5)

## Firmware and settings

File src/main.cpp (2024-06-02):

#include <Arduino.h>
#include "config.h"

enum FunctionTypes
{
    powerOn = PIN_PC3,
    powerOff = PIN_PC4,
    source = PIN_PC2,
    source2 = PIN_PC5
};

int functionPins[] = {PIN_PC3, PIN_PC4, PIN_PC2, PIN_PC5}; // gombok
int ledPins[] = {PIN_PB1, PIN_PD6, PIN_PB2, PIN_PD5};      // ledek

FunctionTypes readInput(bool& lastStatus)
{
    for (int i = 0; i < 4; i++)
    {
        if (!digitalRead(functionPins[i])) // 0-ban aktívak a bemenetek!
        {
            delay(50); //Pergésmentesítés
            if(!digitalRead(functionPins[i])) {
                if (!lastStatus)
                {
                    lastStatus = true;
                    return FunctionTypes(functionPins[i]); // Első gomnyomás
                }
                else
                    return FunctionTypes(0); // Ha volt gombnyomás de már a sokadik
            }
        }
    }
    lastStatus = false;
    return FunctionTypes(0); // Nincs gombnyomás
}

void setupFunctionPins()
{
    for (int i = 0; i < 4; i++)
    {
        pinMode(functionPins[i], INPUT);
    }
}

void setupLedPins()
{
    for (int i = 0; i < 4; i++)
    {
        pinMode(ledPins[i], OUTPUT);
        digitalWrite(ledPins[i], LOW); // Minden led lekapcsolása
    }
}

void setup()
{
    Serial.begin(BAUDRATE);
    delay(50);
    setupFunctionPins();
    setupLedPins();
}

Projector p1(acer);

bool lastStatus = false;
void loop()
{
    switch (readInput(lastStatus))
    {
    case powerOn:
        //digitalWrite(PIN_PD5, HIGH); ide lehet írni led vezérléseket, ki kell találni, hogy mi legyen
        p1.printHexToSerial(p1.turnOnCodes);
        break;

    case powerOff:
        p1.printHexToSerial(p1.turnOffCodes);
        //digitalWrite(PIN_PD5, LOW);
        break;

    case source:
        p1.printHexToSerial(p1.sourceCodes);
        break;

    case source2:
        p1.printHexToSerial(p1.source2Codes);
        break;

    default:
        break;
    }
}

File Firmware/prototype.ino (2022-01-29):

// Sample code for Spakfun Pro Micro
#include "config.h"

#define DEBUG 
#define _MAX_DATA_SIZE 16

struct _SerialSettings // TODO: serial.begin(speed, config) hogy lehet a configot külső headerből kiválasztani (függvény és globál változó vagy más)
{
  int baudRate = BAUDRATE;       // bit per second
  int parity = PARITY;           // on or off
  double stopBit = STOPBIT;      // 1, 1.5 or 2 bit
  int flowControl = FLOWCONTROL; // on or off //TODO: implementálni
} SerialSettings;

struct _ProjectorData
{ // TODO: Lehet a tömb méreteket okosabban kezelni?
  uint8_t TurnOn[_MAX_DATA_SIZE] = TURNON;
  uint8_t TurnOff[_MAX_DATA_SIZE] = TURNOFF;
  uint8_t InputSelectVGA[_MAX_DATA_SIZE] = INPUTSELECTVGA;
  uint8_t InputSelectHDMI[_MAX_DATA_SIZE] = INPUTSELECTHDMI;
} ProjectorData;

void printSettings()
{
  char buffer[255];
  sprintf(buffer,
  "--- SERIAL SETTINGS: ---\nBaud rate: %d\nParity: %d\nStop bit: %f\nFlow control: %s\n",SerialSettings.baudRate, SerialSettings.parity, SerialSettings.stopBit, (SerialSettings.flowControl) ? "On" : "Off");
  Serial.println(buffer);
}

void printHex(uint8_t data[]){
  for (int i = 0; i < _MAX_DATA_SIZE; i++) {
        Serial.write(data[i]);
      }
}

void printData(){
  Serial.println(F("--- PROJECTOR COMMANDS ---"));
  Serial.print(F("Turn On: "));
  printHex(ProjectorData.TurnOn);
  Serial.print(F("Turn Off: "));
  printHex(ProjectorData.TurnOff);
  Serial.print(F("Input select - HDMI: "));
  printHex(ProjectorData.InputSelectHDMI);
  Serial.print(F("Input select - VGA: "));
  printHex(ProjectorData.InputSelectVGA);
}

void setup()
{
  Serial.begin(9600); // USB Debug interface
  //Serial1.begin(SerialSettings.baudRate, SERIAL_8N2);
  #ifdef DEBUG
  pinMode(LED_BUILTIN, OUTPUT); // TODO: 2x villoghat majd bekapcsolva maradhatna debugkor
  printSettings();
  printData();
  #endif
  Serial.println(".");
}

void loop()
{
  Serial.println(".");
  if (Serial.available() > 0) {
  int cmd = Serial.parseInt();
  

  switch (cmd) {
    case 1:
      Serial.println(F("1."));
      printHex(ProjectorData.TurnOn);
      break;
    case 2:
     Serial.println("2.");
     printHex(ProjectorData.TurnOff);
      break;
    case 3:
     Serial.println("3.");
     printHex(ProjectorData.InputSelectHDMI);
      break;
    case 4:
     Serial.println("4.");
     printHex(ProjectorData.InputSelectVGA);
      break;
    default:
      break;
   }
  }
  delay(100);
}

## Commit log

2021-12-11 Sample code added for sparkfun pro micro, Gitignore added for vscode
2022-02-22 Schematic for arduino basic operation and few connectros added
    [projektorosch.kicad_pcb, projektorosch.kicad_sch]
2022-03-01 add buttons, and the connections of max232
    [projektorosch.kicad_sch]
2022-03-07 Improvements, add overvoltage and overcurrent protection
    [projektorosch.kicad_sch]
2022-03-15 assign footprints
    [projektorosch.csv, projektorosch.kicad_pcb]
2022-03-23 design pcb - first try
    [projektorosch.kicad_pcb, projektorosch.kicad_sch]
2022-03-25 redesign layout for attiny3216
    [projektorosch.kicad_pcb, projektorosch.kicad_sch]
2024-03-05 SEM ProjektoroSCH Revision 2
    [doboz_v1.FCStd, doboz_v2.FCStd, doboz_v3.FCStd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]
2024-03-06 Remove PCB fixer spikes from Doboz
    [doboz_v4.FCStd]
2024-04-07 Doboz v5
    [doboz_v5_also.scad, doboz_v5_also.stl, doboz_v5_felso.scad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]
2024-04-07 Doboz v6: -Szélesség növelve -Felfogató lenti hengerek megnagyobbítva -Lekerekítések éleknél, sarkoknál -Nyákot odaszorító dolgok
    [doboz_v4-elektronika_3d.stl, doboz_v6_also.scad, doboz_v6_also.stl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]
2024-04-08 Doboz v6 fix
    [doboz_v6_also.scad, doboz_v6_also.stl, doboz_v6_felso.scad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]
2024-04-23 Doboz v6.2 -félautomata méretezés javítások -méret finomhangolások próbanyomtatás alapján
    [doboz_v6_also.scad, doboz_v6_also.stl, doboz_v6_felso.scad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]
2024-06-02 Majdnem teljesen kész kód
    Acer és Benq projektorokra készek a műveletek, LED vezérlést kell kitalálni, hogy hogyan legyen, és azt onnantól pár sor belekódolni.
    NEC projektor azóta sem bírtam működésre, de először legyen kész és felszerelve az acer és a benq.
